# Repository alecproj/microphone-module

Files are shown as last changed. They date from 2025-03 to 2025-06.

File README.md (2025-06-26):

<div align="center">

# Smart Home Microphone Module
English | [Русский](./README.ru.md)
</div>

**Smart Home Microphone Module** is a compact IoT device based on the ESP32-S3 microcontroller, designed for use in voice-controlled systems, audio monitoring, and integration with smart-home infrastructure. The device captures ambient sound, isolates voice data, processes it, and transmits it over a distributed network.

> [!NOTE]  
> This project is based on the [voice_activity_detection](https://github.com/espressif/esp-skainet/tree/master/examples/voice_activity_detection) example from Espressif’s esp-skainet repository.

# Overview

The project comprises the following components:
- [Microphone Module](#microphone-module) (source code, schematic, PCB layout, enclosure)
- [Server](#server) (server-side source code)
- [voice_activity_detection Example](#voice_activity_detection-example) from Espressif, adapted for DevKit ESP32-S3 with one or two INMP441 MEMS microphones

## Microphone Module

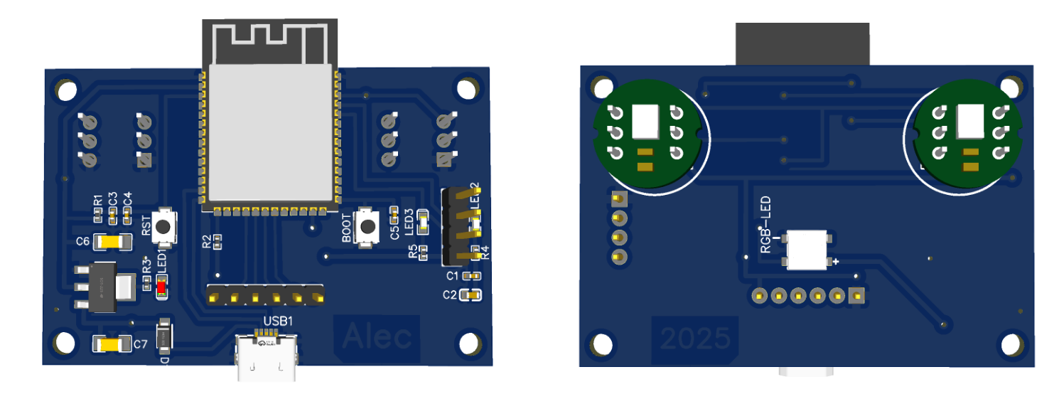
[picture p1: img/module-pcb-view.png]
Microphone module printed circuit board
 
The core components of the device are the `ESP32-S3-WROOM-N16R8` module and two I²S MEMS microphones `INMP441`.

> [!WARNING]  
> This project works **only** with an ESP32 variant that supports **at least 4 MB of PSRAM**!

The module reads audio data from the I²S microphones and processes it using Espressif’s **Audio Front End ([AFE](https://docs.espressif.com/projects/esp-sr/en/latest/esp32s3/audio_front_end/README.html))**. During processing, it performs **Voice Activity Detection (VAD)** and **Noise Suppression (NS)**. The voice data then undergoes **Automatic Gain Control (AGC)**, is converted to mono, packaged into **RTP packets**, and sent to the server over Wi-Fi via **UDP**.

Schematic of AFE audio processing:  
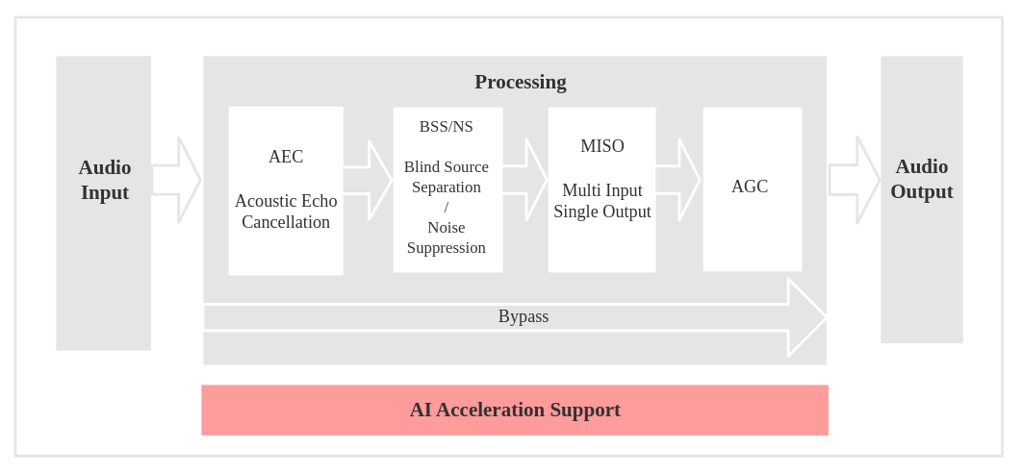
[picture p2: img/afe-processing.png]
AFE audio processing schematic


The project also includes a server application that runs on the local network and performs **speech recognition**.

Key features of the device:
-  Audio processing: VAD / NS / AGC / MISO
-  Logging processed voice data to an SD card (for debugging)
-  Transmitting only voice-active raw PCM data over Wi-Fi (UDP/RTP)

> [!TIP]  
> You can easily reproduce this on a breadboard and test it yourself.  
> Check the [module/](./module) directory for the microphone module’s source code and its **README** with quick-start setup instructions.

### Schematic

> [!CAUTION]  
> There may be errors in the schematic or PCB layout. Before fabricating the PCB, we recommend consulting a professional!  
> See the [implementation notes](./pcb/README.md).

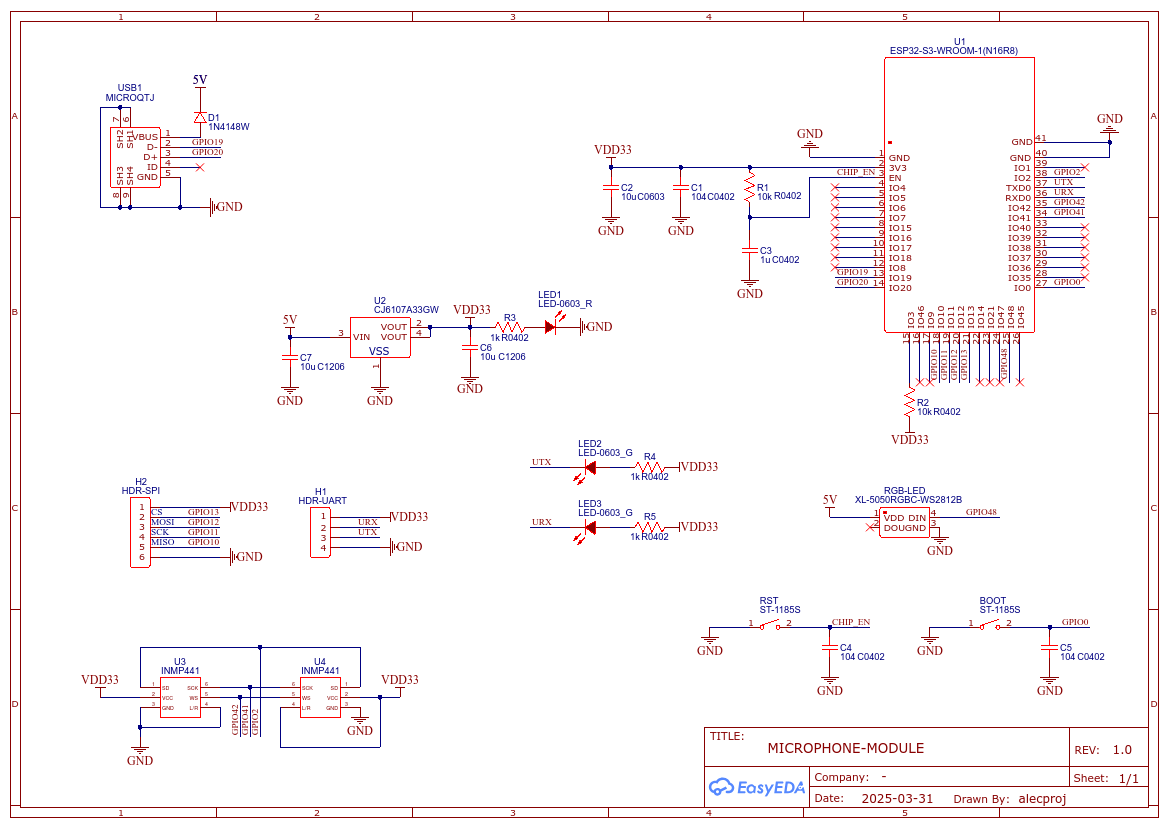
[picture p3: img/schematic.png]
Schematic diagram of the device


### Enclosure

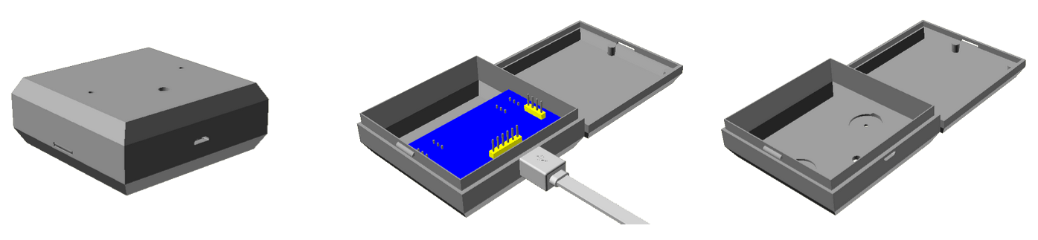
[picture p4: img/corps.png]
Enclosure of the device


## Server

The **server application**, written in Python, receives RTP packets from the device over the local network. Depending on user configuration, it can:
- play back the incoming audio in real time,
- save it to a file,
- perform offline speech recognition using the [VOSK API](https://github.com/alphacep/vosk-api) framework.

> [!TIP]  
> See the [server/](./server) directory for the server application’s source code and its **README** with quick-start setup instructions.

## voice_activity_detection example

The original **VAD** example from Espressif’s [esp-skainet](https://github.com/espressif/esp-skainet) repository supports only official evaluation boards (Korvo, Eye, etc.). In this project, it has been extended to run on **custom boards** (including the ESP32 DevKit) with one or two **INMP441** microphones (or other I²S MEMS mics).

> [!TIP]  
> See the [examples/voice_activity_detection](./examples/voice_activity_detection) directory for the example’s description, source code, and its **README** with quick-start setup instructions.

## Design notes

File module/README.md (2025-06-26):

<div align="center">

# Module Firmware
English | [Русский](./README.ru.md)
</div>

# Overview

This section covers the ESP32-S3 firmware implementing the Smart Home Microphone Module with the following functionality:
- 🎙️ Audio capture via I²S microphone (e.g., INMP441) with multi-channel input support
- 🧠 Audio processing using Espressif’s ESP-SR (Speech Recognition) library:
- 🧠 VAD (Voice Activity Detection)    
- 🌐 Audio transmission over the network using RTP and UDP protocols
- 💾 Debug logging of raw PCM data to an SD card (optional)

### Key Technologies

- [ESP-IDF](https://github.com/espressif/esp-idf) – Development framework for ESP32
- [ESP-SR](https://github.com/espressif/esp-sr) – Espressif’s audio-processing library
- [RTP](https://en.wikipedia.org/wiki/Real-time_Transport_Protocol) – Real-time audio transport protocol
- [FATFS](https://docs.espressif.com/projects/esp-idf/en/v5.4.2/esp32s3/api-reference/storage/fatfs.html) – File system for SD-card access
- [FreeRTOS](https://docs.espressif.com/projects/esp-idf/en/v5.4.2/esp32s3/api-reference/system/freertos.html) – Real-time OS for multi-core processing

### Use Cases

1. Voice-control systems with remote processing
2. Lecture-recording devices streaming to a server
3. Real-time audio-monitoring systems

### Implementation Highlights

1. Dual-core architecture:
    ```c
    xTaskCreatePinnedToCore(&feed_Task, ...);  // Core 0: capture
    xTaskCreatePinnedToCore(&fetch_Task, ...); // Core 1: processing
    ```    
2. Efficient memory management:
    - Statically allocated buffers
    - Ring buffers for audio data
    - Minimal data copying
3. Fault tolerance:
    - Packet-integrity checks
    - Automatic driver reinitialization
    - Buffer-overflow protection

### Operation Modes

1. **Direct streaming to server**  
    Module → Wi-Fi → RTP/UDP → Recognition server
2. **Local storage**  
    Module → SD Card
3. **Hybrid mode**  
    Module → (Network + SD Card) in parallel

### Firmware Architecture Diagram

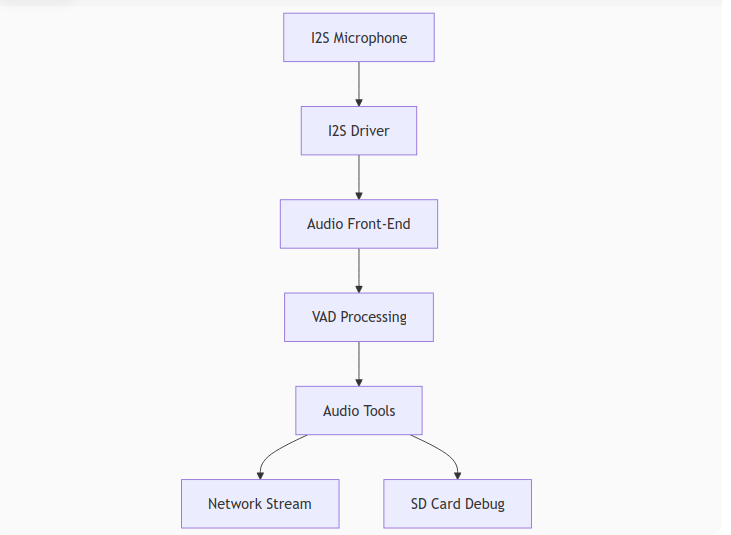
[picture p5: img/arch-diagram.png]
Firmware Architecture Diagram

# Get started

## Hardware Preparation

You will need:
- An ESP32 development board with **at least 4 MB PSRAM** (recommended **ESP32-S3-N16-R8**)
- Two **INMP441** microphones
- An SPI SD-card adapter (_optional, for debugging_)

### Microphone Connection

Wire the microphones as shown below:  
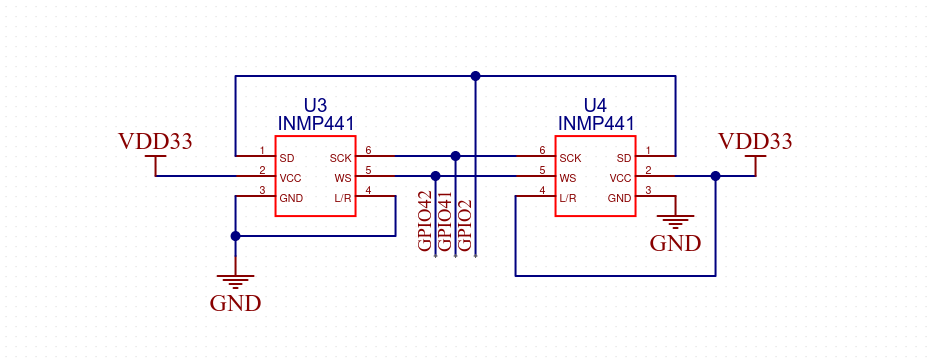
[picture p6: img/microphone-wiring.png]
Microphone Wiring


**Left microphone pinout:**

|Microphone Pin|ESP32-S3 Pin|
|---|---|
|SD|GPIO2|
|VCC|3v3|
|GND|GND|
|SCK|GPIO41|
|WS|GPIO42|
|L/R|GND|

**Right microphone pinout:**

|Microphone Pin|ESP32-S3 Pin|
|---|---|
|SD|GPIO2|
|VCC|3v3|
|GND|GND|
|SCK|GPIO41|
|WS|GPIO42|
|L/R|3v3|

> [!NOTE]  
> You can change the microphone pin assignments in [`module/i2s/i2s_input.h`](./i2s/i2s_input.h) under the `I2S interface GPIO pin assignments` section.

### SD-Card Adapter Connection

**Adapter pinout:**

|Adapter Pin|ESP32-S3 Pin|
|---|---|
|CS|GPIO13|
|SCK|GPIO11|
|MOSI|GPIO12|
|MISO|GPIO10|
|VCC|3v3|
|GND|GND|

> [!NOTE]  
> You can change the SD-card adapter pin assignments in [`module/sd_card/sdcard.h`](./sd_card/sdcard.h) under the `SD Card SPI interface configuration` section.

## Software Preparation

### Install ESP-IDF

To flash the microcontroller and configure the project, install the [ESP-IDF framework](https://docs.espressif.com/projects/esp-idf/en/v5.4.2/esp32s3/get-started/index.html) version **5.0 or newer**.

### Project Setup

1. Clone the repository:
	```sh
    git clone https://github.com/alecproj/microphone-module.git
	```
2. If you plan to use the module with your computer acting as the server on the local network, it’s recommended to first [install and configure the server](../server/README.md).
3. Change into the module directory:
    ```sh
    cd microphone-module/module
    ```
4. Set up ESP-IDF environment variables (see the [official guide](https://docs.espressif.com/projects/esp-idf/en/v5.4.2/esp32s3/get-started/linux-macos-setup.html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)).
5. Configure the project:
    ```sh
    idf.py set-target esp32s3
    idf.py menuconfig
    ```
    In the **Example Connection Configuration** section, set your Wi-Fi parameters if you plan to stream to the server.
6. In [`./main/main.c`](./main/main.c), adjust the configuration switches as needed:
    ```c
    // Configuration switches
    #define SD_FOR_DEBUG_EN 0  // Enable SD card logging for debug (0=disabled)
    #define NETWORK_EN      1  // Enable network streaming (1=enabled)
    ```

> [!NOTE]  
> For logging to SD card, ensure the SPI-SD adapter is connected.

7. In [`../network/network_stream.h`](./network/network_stream.h), set your computer’s IP address:
    ```c
    #define SERVER_IP "192.168.0.175"  // Default server IP address
    ```
8. Build and flash the board:
    ```sh
    idf.py build
    idf.py flash monitor
    ```

# Troubleshooting

## Wi-Fi Connection Issues

1. Double-check your settings in the **Example Connection Configuration** menuconfig. Ensure the **WiFi scan threshold** matches your network’s parameters.
2. Make sure no metallic objects (wires, breadboards, PCB copper areas, etc.) are near the ESP32 antenna.
3. Reserve a static IP for the ESP32 in your router’s DHCP settings.
4. Run the official ESP-IDF examples [scan](https://github.com/espressif/esp-idf/tree/master/examples/wifi/scan) and [station](https://github.com/espressif/esp-idf/tree/master/examples/wifi/getting_started/station) to find the optimal module placement.

> [!NOTE]  
> Common stability issues with the ESP32’s onboard antenna stem from nearby metal objects. For robust connectivity, consider using a module with an external antenna.

## SD-Card SPI Adapter Issues

1. Verify the adapter wiring against the schematic and the settings in [`module/sd_card/sdcard.h`](./sd_card/sdcard.h) under `SD Card SPI interface configuration`.
2. Use the shortest possible wires (no longer than 10 cm).
3. Manually format the SD card as FAT32 using your OS tools.
4. Prefer SD cards up to 8 GB in capacity.
5. If issues persist, lower the SPI bus speed (see the sdspi example README in ESP-IDF: [sdspi](https://github.com/espressif/esp-idf/tree/master/examples/storage/sd_card/sdspi)).

> [!NOTE]  
> Not all SD cards support SPI mode. Check your card’s datasheet. Card-adapter compatibility can vary, so you may need to test cards from different manufacturers.
# TODO

- Add LED status indication
- Implement custom Wi-Fi connection logic
- Integrate automatic gain control (AGC)
- Add project configuration via `Kconfig`
- Implement an OTA update system

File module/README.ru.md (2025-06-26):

<div align="center">

# Прошивка модуля
[English](./README.md) | Русский
</div>

# Обзор

Данный раздел посвящен прошивке для ESP32-S3, которая реализует микрофонный модуль умного дома со следующей функциональностью:
- 🎙️ Захват аудио через I2S-микрофон (например, INMP441) с поддержкой многоканального ввода
- 🧠 Обработка звука с использованием библиотеки ESP-SR (Speech Recognition) от Espressif:
- 🧠 VAD (Voice Activity Detection) для обнаружения речи
- 🌐 Передача аудио по сети с использованием протоколов RTP и UDP
- 💾 Отладочная запись сырых PCM-данных на SD-карту (опционально)

### Ключевые технологии

- [ESP-IDF](https://github.com/espressif/esp-idf) - Фреймворк для разработки под ESP32
- [ESP-SR](https://github.com/espressif/esp-sr) - Библиотека обработки звука от Espressif
- [RTP](https://en.wikipedia.org/wiki/Real-time_Transport_Protocol) - Протокол реального времени для передачи аудио
- [FATFS](https://docs.espressif.com/projects/esp-idf/en/v5.4.2/esp32s3/api-reference/storage/fatfs.html) - Файловая система для работы с SD-картой
- [FreeRTOS](https://docs.espressif.com/projects/esp-idf/en/v5.4.2/esp32s3/api-reference/system/freertos.html) - Операционная система реального времени для многоядерной обработки
### Сфера применения

1. Системы голосового управления с удаленной обработкой
2. Устройства для записи лекций с передачей на сервер
3. Системы аудиомониторинга в реальном времени

### Особенности реализации

1. Двухядерная архитектура:
```c
    xTaskCreatePinnedToCore(&feed_Task, ...);  // Core 0: захват
    xTaskCreatePinnedToCore(&fetch_Task, ...); // Core 1: обработка
```
2. Эффективное управление памятью:
    - Статическое выделение буферов
    - Кольцевые буферы для аудиоданных
    - Минимизация копирования данных
3. Отказоустойчивость:
    - Проверка целостности пакетов
    - Автоматическая реинициализация драйверов
    - Защита от переполнения буферов

### Сценарии использования

1. **Прямая передача на сервер**:
	Module → Wi-Fi → RTP/UDP → Сервер распознавания
2. **Локальное хранение**:
	Module → SD Card
3. **Гибридный режим**:
	Module → (Сеть + SD Card) параллельно

### Диаграма архитектуры прошивки
Диаграма архитектуры прошивки
# Быстрый старт
## Подготовка оборудования

Вам понадобится:
- Отладочная плата с микроконтроллером **ESP32** с поддержкой **PSRAM не менее 4 МБ** (рекомендуется **ESP32-S3-N16-R8**)
- Два микрофона **INMP441**
- SPI-адаптер SD-карт (*опционально, для отладки*)
### Подключение микрофонов
Подключите микрофоны согласно приведённой ниже схеме:
Схема подключения микрофонов

**Таблица подключения левого микрофона:**

| Контакт микрофона | Контакт ESP32-S3 |
| --- | --- |
| SD | GPIO2 |
| VCC | 3v3 |
| GND | GND |
| SCK | GPIO41 |
| WS | GPIO42 |
| L/R | GND |

**Таблица подключения правого микрофона:**

| Контакт микрофона | Контакт ESP32-S3 |
| --- | --- |
| SD | GPIO2 |
| VCC | 3v3 |
| GND | GND |
| SCK | GPIO41 |
| WS | GPIO42 |
| L/R | 3v3 |
>[!NOTE]
>Изменить назначение пинов микрофонов можно в файле [`module/i2s/i2s_input.h`](./i2s/i2s_input.h) в разделе `I2S interface GPIO pin assignments`.
### Подключение адаптера SD-карт
**Таблица подключения адаптера:**

| Контакт адаптера | Контакт ESP32-S3 |
| --- | --- |
| CS | GPIO13 |
| SCK | GPIO11 |
| MOSI | GPIO12 |
| MISO | GPIO10 |
| VCC | 3v3 |
| GND | GND |
>[!NOTE]
>Изменить пины подключения SD-адаптера можно в файле [`module/sd_card/sdcard.h`](./sd_card/sdcard.h) в разделе `SD Card SPI interface configuration`
## Подготовка ПО
### Установка ESP-IDF

Для прошивки микроконтроллера и конфигурации проекта необходим установленный фреймворк [ESP-IDF](https://docs.espressif.com/projects/esp-idf/en/v5.4.2/esp32s3/get-started/index.html) версии **не ниже 5.0**.

### Подготовка проекта

1. Клонируйте репозиторий проекта:
```sh
git clone https://github.com/alecproj/microphone-module.git
```
2. Если вы хотите использовать модуль для взаимодействия с сервером, в роли которого будет выступать ваш компьютер в локальной сети, то рекомендуется сначала [установить и настроить сервер](../server/README.ru).
3. Перейдите в директорию модуля:
```sh
cd microphone-module/module
```
4. Настройте переменные среды ESP-IDF (см. [официальное руководство](https://docs.espressif.com/projects/esp-idf/en/v5.4.2/esp32s3/get-started/linux-macos-setup.html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))
5. Выполните настройку проекта:
```sh
idf.py set-target esp32s3
idf.py menuconfig
```
В разделе `Example Connection Configuration` укажите параметры сети, если планируется подключение к серверу по Wi-Fi.
6. Перейдите в папку `./main`, откройте файл [`main.c`](./main/main.c) и настройте параметры:
```c
// Configuration switches
#define SD_FOR_DEBUG_EN 0  // Enable SD card logging for debug (0=disabled)
#define NETWORK_EN 1       // Enable network streaming (1=enabled)
```
>[!NOTE]
>Для записи на SD-карту должен быть подключён SPI-адаптер.

7. Перейдите в папку `../network`, откройте файл [`network_stream.h`](./network/network_stream.h) и укажите ip-адрес вашего компьютера:
```c
#define SERVER_IP "192.168.0.175"     // Default server IP address
```
8. Скомпилируйте проект и прошейте плату:
```sh
idf.py build
idf.py flash monitor
```
# Устранение неисправностей
## Проблемы с Wi-Fi соединением

1. Перепроверьте корректность настроек в разделе `Example Connection Configuration` menuconfig. Значения в разделе `WiFi scan threshold` должны соответствовать параметрам вашей WiFi сети.
2. Убедитесь, что рядом с антенной ESP32 нет металлических предметов (включая провода, макетные платы и другие элементы, способные экранировать сигнал).
3. Зарезервируйте статический IP-адрес для ESP32 в настройках DHCP-сервера вашего роутера.
4. Запустите официальные примеры [scan](https://github.com/espressif/esp-idf/tree/master/examples/wifi/scan) и [station](https://github.com/espressif/esp-idf/tree/master/examples/wifi/getting_started/station) из репозитория ESP-IDF и подберите оптимальное расположение модуля.

> [!NOTE]  
> Наиболее распространённые проблемы со стабильностью Wi-Fi при использовании ESP32 с интегрированной антенной связаны с экранирующими объектами рядом (макетные платы, провода, металлические полигоны). Рекомендуется использовать модули с внешней антенной для надёжного соединения.
## Проблемы с SPI-адаптером SD-карты

1. Проверьте правильность подключения адаптера согласно схеме и настройкам в файле [`module/sd_card/sdcard.h`](./sd_card/sdcard.h), раздел `SD Card SPI interface configuration`.
2. Используйте максимально короткие провода (не более 10 см).
3. Отформатируйте SD-карту вручную в файловую систему FAT32 средствами вашей операционной системы.
4. По возможности используйте SD-карты объёмом до 8 ГБ.
5. Попробуйте снизить скорость передачи данных по SPI (см. [README примера sdspi](https://github.com/espressif/esp-idf/tree/master/examples/storage/sd_card/sdspi)).

> [!NOTE]  
> Не все SD-карты поддерживают режим SPI. Ознакомьтесь с технической документацией вашей карты. Также возможны проблемы совместимости между конкретной картой и адаптером. Иногда необходимо протестировать несколько карт разных производителей, прежде чем найти совместимую.

# TODO

- Добавить светодиодную индикацию состояния (LED-индикация)
- Реализовать собственную логику подключения к Wi-Fi
- Внедрить автоматическую регулировку усиления (AGC, Auto Gain Control)
- Добавить возможность конфигурации проекта через `Kconfig`
- Внедрить систему OTA-обновлений

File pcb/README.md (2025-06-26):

<div align="center">

# Printed Circuit Board
English | [Русский](./README.ru.md)
</div>

> [!CAUTION]  
> There may be errors in the schematic or PCB layout. Before fabricating the PCB, we recommend consulting a professional! 

> [!WARNING]  
> Please read the [Known Issues](#-known-issues) section!

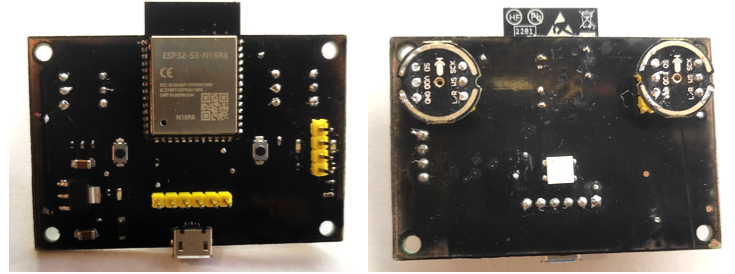
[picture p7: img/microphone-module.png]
Microphone Module


# Implementation Notes

## Components

The use of 0402 SMD components was chosen to reduce the cost of home PCB manufacturing. All passive components were desoldered from a widely available Chinese DevKit C-1 board (a clone of the original Espressif module). Other than that development board and two INMP441 microphones, no additional components are needed to build this PCB at home.

> [!NOTE]  
> The schematic and datasheet for the reference board version can be found in the repository:  
> [https://github.com/rtek1000/YD-ESP32-23.git](https://github.com/rtek1000/YD-ESP32-23.git)  
> This design served as a base for the microphone module.

## 🚨 Known Issues

The PCB layout does not fully follow the [Espressif guidelines for placing ESP32-S3-WROOM-1 modules](https://docs.espressif.com/projects/esp-hardware-design-guidelines/en/latest/esp32s3/pcb-layout-design.html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). As a result, the board exhibits degraded Wi-Fi signal quality. Ground planes, traces, and components located near the right side of the onboard antenna create parasitic structures and partially shield the signal.

### Possible Solutions:

- **Replace the module with [ESP32-S3-WROOM-1U](https://www.espressif.com/sites/default/files/documentation/esp32-s3-wroom-1_wroom-1u_datasheet_en.pdf)**, which supports external antennas. Plan antenna placement accordingly.
- **Redesign the PCB layout**: remove ground planes and traces in the antenna zone, or rework the component placement based on Espressif's recommendations.

> [!TIP]  
> Even with perfect layout, the onboard antenna is limited in performance. Therefore, **switching to the external-antenna variant (WROOM-1U) is the recommended approach**.

## PCB Schematic

PCB Schematic

## PCB Layout

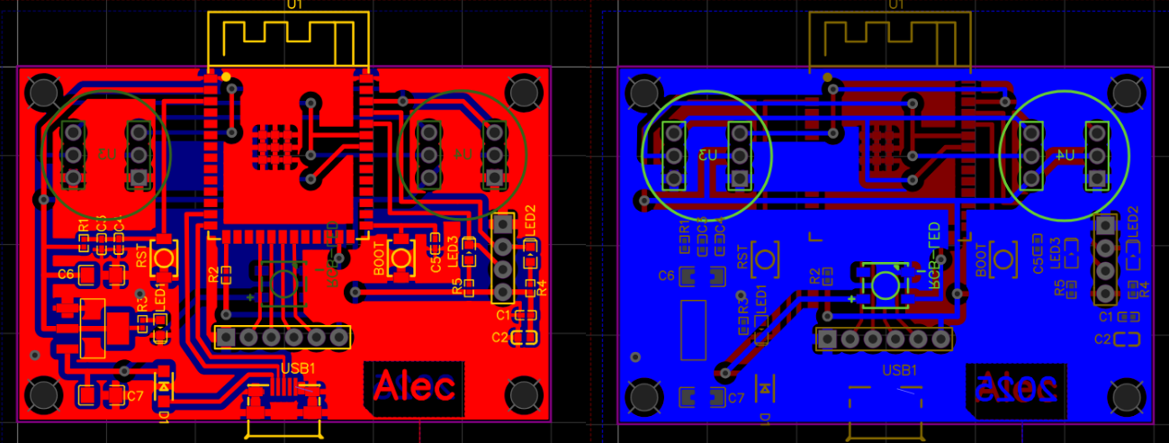
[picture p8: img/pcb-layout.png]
PCB Layout


## PCB Manufacturing Process

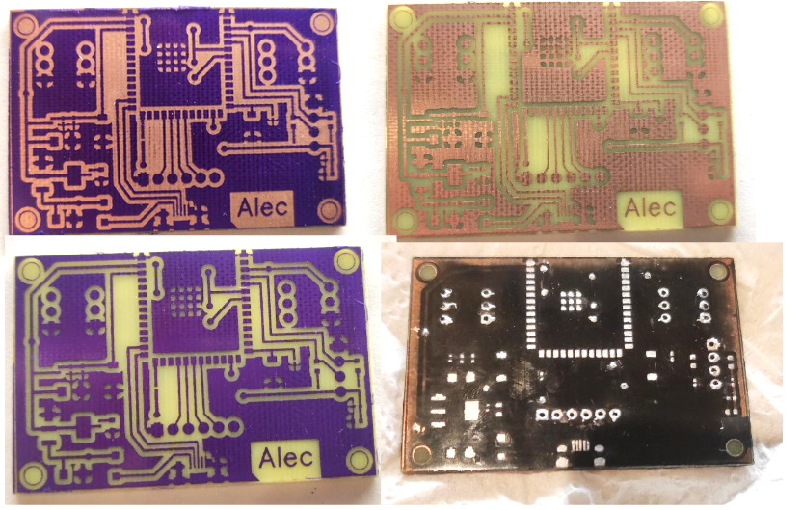
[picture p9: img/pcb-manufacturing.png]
PCB Manufacturing Process


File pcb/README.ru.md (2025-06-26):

<div align="center">

# Печатная плата
[English](./README.md) | Русский
</div>

> [!CAUTION]
> Схема и разводка печатной платы могут содержать ошибки. Перед воспроизведением печатной платы рекомендуется проконсультироваться с профессионалом!

> [!WARNING]
> Ознакомьтесь с содержимым раздела [Известные проблемы](#-известные-проблемы)!

Микрофонный модуль
# Заметки о реализации

## Компоненты

Выбор SMD-компонентов форм-фактора 0402 обусловлен стремлением удешевить производство печатной платы в домашних условиях. Все обвязочные компоненты были перепаяны с популярной на китайском рынке отладочной платы DevKit C-1 (клон оригинального модуля от Espressif). Помимо такой отладочной платы и двух микрофонов INMP441, для домашнего изготовления этой печатной платы дополнительных компонентов не потребуется.

>[!NOTE]
Схема и даташит к используемой версии платы размещены в репозитории:  
[https://github.com/rtek1000/YD-ESP32-23.git](https://github.com/rtek1000/YD-ESP32-23.git)  
Они были взяты за основу при разработке микрофонного модуля.
## 🚨 Известные проблемы

При разводке печатной платы не были учтены [рекомендации Espressif по размещению модулей ESP32-S3-WROOM-1](https://docs.espressif.com/projects/esp-hardware-design-guidelines/en/latest/esp32s3/pcb-layout-design.html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). В результате на разработанной плате наблюдаются проблемы с качеством Wi-Fi сигнала. Земляные полигоны, дорожки и компоненты, расположенные справа от антенны, создают паразитные антенны и частично экранируют сигнал.

### Возможные решения:

- **Заменить модуль на [ESP32-S3-WROOM-1U](https://www.espressif.com/sites/default/files/documentation/esp32-s3-wroom-1_wroom-1u_datasheet_en.pdf)** (с возможностью подключения выносной антенны) и продумать её размещение в корпусе.
- **Переработать топологию печатной платы**: удалить земляные полигоны и дорожки в зоне антенны, либо полностью изменить расположение компонентов в соответствии с рекомендациями Espressif.

> [!TIP] 
> Учитывая ограниченные возможности встроенной антенны даже при идеальной разводке, **наиболее предпочтительным вариантом является переход на модуль с внешней антенной (WROOM-1U)**.

## Схема печатной платы

Схема печатной платы
## Разводка печатной платы

Разводка печатной платы
## Процесс изготовления печатной платы

Процесс изготовления печатной платы

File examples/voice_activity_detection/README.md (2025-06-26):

<div align="center">

# Voice Activity Detection
English | [Русский](./README.ru.md)
</div>

This example is used to test VAD (Voice Activity Detection). Now two types of VAD are supported: WebRTC VAD and Espressif's vadnet1. You can select the desired version through menuconfig. Compared to WebRTC noise, vadnet1 can filter out more noise, but it also consumes more CPU resources.
# Quick Start

## Hardware Preparation

To run this example, you need to have an **ESP32** or **ESP32-S3** (ESP32-S3 recommended) development board with one or two **INMP441** microphones (or other I²S MEMS mics).
## Software Preparation
### Microphone Module

Clone this project as follows:
```sh
git clone https://github.com/alecproj/microphone-module.git
```
Change into the example directory:
```sh
cd microphone-module/examples/voice_activity_detection
```
### ESP-IDF

 [ESP-IDF v5.0](https://github.com/espressif/esp-idf/tree/release/v5.0) (or newer) are supported. If you had already configured ESP-IDF before, and do not want to change your existing one, you can configure the `IDF_PATH` environment variable to the path to ESP-IDF. 

>[!NOTE]
For details on how to set up the ESP-IDF, please refer to [ESP-IDF framework](https://docs.espressif.com/projects/esp-idf/en/v5.4.2/esp32s3/get-started/index.html)
### Configure 

Select board and wake words
```
idf.py set-target esp32s3
idf.py menuconfig

# Select audio board
Audio Media HAL -> Audio hardware board -> ESP32-S3-1mic

# Load vadnet1 model
ESP Speech Recognition -> Select voice activity detection -> voice activity detection (vadnet1 medium)
```
### Setting

You can set the following parameters in the config file:
```
    vad_init;           // Whether to init vad
    vad_mode;           // The value can be: VAD_MODE_0, VAD_MODE_1, VAD_MODE_2, VAD_MODE_3, VAD_MODE_4
                        // The larger the mode, the higher the speech trigger probability.

    vad_model_name;     // The model name of vad, If it is null, WebRTC VAD will be used.
    vad_min_speech_ms;  // The minimum duration of speech in ms. It should be bigger than 32 ms, default: 128 ms
    vad_min_noise_ms;   // The minimum duration of noise or silence in ms. It should be bigger than 64 ms, default: 1000 ms
    vad_delay_ms;       // The delay of the first speech frame in ms, default: 128 ms
                            // If you find vad cache can not cover all speech, please increase this value.
```

There are two issues in the VAD settings that can cause a delay in the first frame trigger of speech.
1. The inherent delay of the VAD algorithm itself. VAD cannot accurately trigger speech on the first frame and may delay by 1 to 3 frames.
2. To avoid false triggers, the VAD is triggered when the continuous trigger duration reaches the `vad_min_speech_ms` parameter in AFE configuation.
Due to the above two reasons, directly using the first frame trigger of VAD may cause the first word to be truncated. 
To avoid this situation, AFE V2.0 has added a VAD cache. You can determine whether a VAD cache needs to be saved by checking the vad_cache_size.

### build&flash

Build the project and flash it to the board, then run the monitor tool to view the output via serial port:

```
idf.py flash monitor 
```

(To exit the serial monitor, type ``Ctrl-]``.)

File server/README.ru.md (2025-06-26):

<div align="center">

# Аудио сервер
[English](./README.md) | Русский
</div>

# Обзор

**Сервер для приёма голосовых аудиоданных** обладает следующими ключевыми функциями:
- 🌐 Приём аудиопотока по UDP (протокол RTP)
- 🔊 Воспроизведение аудио в реальном времени с использованием PyAudio
- 💾 Запись сырого аудиопотока в файл формата PCM
- 🎙️ Офлайн-распознавание речи с помощью [Vosk API](https://github.com/alphacep/vosk-api)
- ⚙️ Конфигурация через аргументы командной строки
- 🛡️ Корректная обработка сигналов завершения (SIGINT, SIGTERM)

### Зависимости
- Python 3.10+ (проверьте версию: `python --version`)
- [VoskAPI](https://alphacephei.com/vosk/) 
- [PyAudio](https://people.csail.mit.edu/hubert/pyaudio/)
- [NumPy](https://numpy.org)
- [RTP](https://github.com/bbc/rd-apmm-python-lib-rtp)
# Быстрый старт
## Установка

1. Клонируйте репозиторий:
```bash
git clone https://github.com/alecproj/microphone-module
cd microphone-module/server
```
2. (Опционально) Создайте виртуальное окружение:
```bash
python -m venv pyvenv
# Для Linux/macOS:
source pyvenv/bin/activate
# Для Windows:
.\pyvenv\Scripts\activate
```
3. Установите зависимости:
```bash
pip install -r requirements.txt
```
4. Установите модель Vosk:
```bash
# Замените модель при необходимости
wget https://alphacephei.com/vosk/models/vosk-model-ru-0.42.zip
unzip vosk-model-ru-0.42.zip
mv vosk-model-ru-0.42 model
```
> [!TIP] 
> Доступные модели: [alphacephei.com/vosk/models](https://alphacephei.com/vosk/models)

> [!NOTE]
> Если у вас нет `wget`, скачайте модель вручную и распакуйте в папку `model`.

5. Укажите путь к модели Vosk в файле [`server.py`](./server.py):
```python
    VOSK_MODEL_PATH: str = "model/vosk-model-ru-0.42"
```
## Использование

Запустите сервер, выполнив:
```bash
python server.py [-h] [--disable-recognition] [--disable-playback] [--disable-file-write] [--log-level {DEBUG,INFO,WARNING,ERROR,CRITICAL}]
```
**Описание аргументов командной строки:**

| Аргумент | Описание | По умолчанию |
| --- | --- | --- |
| -h, --help | Помощь и завершение | - |
| `--disable-recognition` | Отключить распознавание речи | Включено |
| `--disable-playback` | Отключить воспроизведение аудио | Включено |
| `--disable-file-write`  | Отключить запись аудио в файл (PCM) | Включено |
| `--log-level` | Уровень логирования (DEBUG, INFO, WARNING, ERROR, CRITICAL) | INFO |

**Вывод в консоль при успешном запуске сервера:**
```sh
2025-06-26 16:49:28,664 - RTPServer - INFO - Server started on 0.0.0.0:8765 with settings:
2025-06-26 16:49:28,664 - RTPServer - INFO -  Recognition: True
2025-06-26 16:49:28,665 - RTPServer - INFO -  Playback: True
2025-06-26 16:49:28,665 - RTPServer - INFO -  File write: True
LOG (VoskAPI:ReadDataFiles():model.cc:213) Decoding params beam=13 max-active=7000 lattice-beam=6
LOG (VoskAPI:ReadDataFiles():model.cc:216) Silence phones 1:2:3:4:5:6:7:8:9:10
LOG (VoskAPI:RemoveOrphanNodes():nnet-nnet.cc:948) Removed 1 orphan nodes.
LOG (VoskAPI:RemoveOrphanComponents():nnet-nnet.cc:847) Removing 2 orphan components.
LOG (VoskAPI:Collapse():nnet-utils.cc:1488) Added 1 components, removed 2
LOG (VoskAPI:ReadDataFiles():model.cc:248) Loading i-vector extractor from model/vosk-model-ru-0.42/ivector/final.ie
LOG (VoskAPI:ComputeDerivedVars():ivector-extractor.cc:183) Computing derived variables for iVector extractor
LOG (VoskAPI:ComputeDerivedVars():ivector-extractor.cc:204) Done.
LOG (VoskAPI:ReadDataFiles():model.cc:279) Loading HCLG from model/vosk-model-ru-0.42/graph/HCLG.fst
LOG (VoskAPI:ReadDataFiles():model.cc:297) Loading words from model/vosk-model-ru-0.42/graph/words.txt
LOG (VoskAPI:ReadDataFiles():model.cc:308) Loading winfo model/vosk-model-ru-0.42/graph/phones/word_boundary.int
LOG (VoskAPI:ReadDataFiles():model.cc:315) Loading subtract G.fst model from model/vosk-model-ru-0.42/rescore/G.fst
LOG (VoskAPI:ReadDataFiles():model.cc:317) Loading CARPA model from model/vosk-model-ru-0.42/rescore/G.carpa
LOG (VoskAPI:ReadDataFiles():model.cc:323) Loading RNNLM model from model/vosk-model-ru-0.42/rnnlm/final.raw
2025-06-26 16:49:51,182 - RTPServer - INFO - Recognizer started
```
# Для разработчиков

## Конфигурация

 Основные параметры конфигурации изменяются в коде [`server.py`](./server.py) (класс `Config`), например:
- `HOST` и `PORT` для UDP сервера
- Параметры аудио (формат, каналы, частота дискретизации, размер буфера)
- Путь к модели Vosk (`VOSK_MODEL_PATH`)

```python
class Config:
    HOST: str = "0.0.0.0"
    PORT: int = 8765
    AUDIO_FORMAT: int = pyaudio.paInt16
    CHANNELS: int = 1
    SAMPLE_RATE: int = 16000
    FRAMES_PER_BUFFER: int = 4096 
    MIN_PACKET_LEN: int = 512
    MAX_PACKET_LEN: int = 1024
    LOG_LEVEL: str = "INFO"
    VOSK_MODEL_PATH: str = "model/vosk-model-ru-0.42"
    ENABLE_RECOGNITION: bool = True
    ENABLE_PLAYBACK: bool = True
    ENABLE_FILE_WRITE: bool = True

```
## Советы по отладке

1. Проверка входящего трафика:
```sh
tcpdump -i any udp port 8765 -vv -X
```
2. Прослушивание в обход сервера через ffmpeg
```sh
ffmpeg -f alsa -i default -acodec pcm_s16le -ar 16000 -ac 1 -f rtp rtp://127.0.0.1:8765
```
3. Воспроизведение записанного PCM:
```sh
ffplay -f s16le -ar 16000 TEST.PCM
```
4. Тестирование без сети:
```sh
# В udp_server() после получения данных:
audio_streamer.process_audio(b"\x00" * 2048)  # Генерация тишины
```
# TODO

-  Добавить валидацию источников
-  Внедрить шифрование данных
-  Реализовать мониторинг трафика и других метрик
-  Написать тесты

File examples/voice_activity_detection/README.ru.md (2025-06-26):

<div align="center">

# Обнаружение голосовой активности
[English](./README.md) | Русский
</div>

Этот пример используется для тестирования детекции голосовой активности (Voice Activity Detection, VAD). Поддерживаются два типа VAD: WebRTC VAD и vadnet1 от Espressif. Вы можете выбрать необходимую версию через menuconfig. По сравнению с WebRTC VAD, vadnet1 лучше фильтрует фоновые шумы, однако требует больше ресурсов CPU.

# Быстрый старт

## Подготовка оборудования

Для запуска этого примера вам понадобится плата разработки **ESP32** или **ESP32-S3** (рекомендуется ESP32-S3) с одним или двумя микрофонами **INMP441** (или другими I²S MEMS-микрофонами).

## Подготовка ПО

### Модуль микрофона

Клонируйте этот проект следующей командой:
```sh
git clone https://github.com/alecproj/microphone-module.git
```
Перейдите в директорию примера:
```sh
cd microphone-module/examples/voice_activity_detection
```
### ESP-IDF

Поддерживаются версии [ESP-IDF v5.0](https://github.com/espressif/esp-idf/tree/release/v5.0) или новее. Если вы уже настроили ESP-IDF и не хотите менять существующую конфигурацию, можете указать путь к ESP-IDF через переменную окружения `IDF_PATH`.

> [!NOTE]  
> Для подробностей по установке ESP-IDF см. [документацию ESP-IDF](https://docs.espressif.com/projects/esp-idf/en/v5.4.2/esp32s3/get-started/index.html)

### Конфигурирование

Выберите плату и модель VAD:
```
idf.py set-target esp32s3
idf.py menuconfig

# Выберите аудиоплату
Audio Media HAL -> Audio hardware board -> ESP32-S3-1mic

# Загрузите модель vadnet1
ESP Speech Recognition -> Select voice activity detection -> voice activity detection (vadnet1 medium)
```
### Параметры

В файле конфигурации можно задать следующие параметры:

```c
    vad_init;           // Инициализация VAD
    vad_mode;           // Может принимать значения: VAD_MODE_0, VAD_MODE_1, VAD_MODE_2, VAD_MODE_3, VAD_MODE_4
                        // Чем выше режим, тем выше вероятность срабатывания на речь.

    vad_model_name;     // Имя модели VAD. Если null, используется WebRTC VAD.
    vad_min_speech_ms;  // Минимальная длительность речи в мс. Должна быть больше 32 мс, по умолчанию: 128 мс
    vad_min_noise_ms;   // Минимальная длительность шума или тишины в мс. Должна быть больше 64 мс, по умолчанию: 1000 мс
    vad_delay_ms;       // Задержка до первого фрейма речи в мс, по умолчанию: 128 мс
                        // Если VAD-кеш не покрывает весь фрагмент речи, увеличьте это значение.
```

В настройках VAD есть два фактора, которые могут вызвать задержку срабатывания на первый фрейм речи:
1. Встроенная задержка самого алгоритма VAD. Алгоритм может определить начало речи с задержкой в 1–3 кадра.
2. Во избежание ложных срабатываний VAD срабатывает только при достижении непрерывной длительности речи, указанной в параметре `vad_min_speech_ms`.

Из-за этих причин прямое использование первого фрейма VAD может привести к усечению первого слова. Чтобы этого избежать, в AFE V2.0 добавлен VAD-кеш. Вы можете определить необходимость сохранения кеша по значению `vad_cache_size`.
### Сборка и прошивка

Соберите проект и прошейте плату, затем запустите монитор для просмотра вывода по последовательному порту:
```sh
idf.py flash monitor
```
(Для выхода из монитора нажмите `Ctrl-]`.)

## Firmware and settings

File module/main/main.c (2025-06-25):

#include <stdbool.h>

#include "esp_afe_sr_models.h"
#include "freertos/FreeRTOS.h"
#include "freertos/task.h"
#include "model_path.h"
#include "esp_log.h"
#include "esp_event.h"
#include "nvs_flash.h"
#include "esp_netif.h"
#include "protocol_examples_common.h"

#include "i2s_input.h"
#include "sdcard.h"
#include "audio_tools.h"
#include "network_stream.h"

// Configuration switches
#define SD_FOR_DEBUG_EN 0  // Enable SD card logging for debug (0=disabled)
#define NETWORK_EN 1       // Enable network streaming (1=enabled)

static esp_afe_sr_iface_t *afe_handle = NULL;
static const char* TAG = "module";
#if SD_FOR_DEBUG_EN
static FILE* fd = NULL;
#endif // SD_FOR_DEBUG_EN
#if NETWORK_EN
static network_data_t network_data = {0};
#endif // NETWORK_EN

/**
 * @brief Process audio data and stream to output targets
 * 
 * @param audio_data Input audio data structure
 * 
 * Performs:
 * 1. Downmix to mono (if multichannel input)
 * 2. SD card debug logging (if enabled)
 * 3. Network streaming (if enabled)
 * 4. Memory cleanup
 */
void postprocess_and_stream(audio_data_t* audio_data)
{
    esp_err_t rv = ESP_OK;
    audio_data_t output = {0};

    if (!audio_data)
    {
        ESP_LOGE(TAG, "An invalid pointer was passed to the "
                      "post processing function.");
        return;
    }

    if (audio_data->data_channels > 1)
    {
        rv = downmix_to_mono(*audio_data, &output);
        if (rv != ESP_OK)
        {
            ESP_LOGE(TAG, "An error (%s) occurred during post processing.", 
                     esp_err_to_name(rv));
            return;
        }
    }

#if SD_FOR_DEBUG_EN
    sdcard_write(output.data, 1, output.data_size, fd);
#endif // SD_FOR_DEBUG_EN

#if NETWORK_EN
    udp_send_pcm(output.data, output.data_size, &network_data);
#endif // NETWORK_EN

    free(output.data);
    output.data = NULL;
}

/**
 * @brief Task for feeding audio data to AFE (Audio Front-End)
 * 
 * @param arg AFE data handle (esp_afe_sr_data_t)
 * 
 * Continuously:
 * 1. Reads audio from I2S input
 * 2. Feeds data to AFE processing pipeline
 */
void feed_Task(void *arg)
{
    esp_afe_sr_data_t *afe_data = arg;
    int feed_chunksize = afe_handle->get_feed_chunksize(afe_data);
    // TODO: configuration compliance check
    int feed_nch = afe_handle->get_feed_channel_num(afe_data);
    int16_t *feed_buff = (int16_t *) malloc(feed_chunksize * feed_nch * sizeof(int16_t));
    assert(feed_buff);

    while (1)
    {
        i2s_input_get_feed_data(
            feed_buff, 
            feed_chunksize * feed_nch * sizeof(int16_t)
        );
        afe_handle->feed(afe_data, feed_buff);
    }
    
    if (feed_buff)
    {
        free(feed_buff);
        feed_buff = NULL;
    }
    vTaskDelete(NULL);
}

/**
 * @brief Task for fetching processed audio from AFE
 * 
 * @param arg AFE data handle (esp_afe_sr_data_t)
 * 
 * Continuously:
 * 1. Fetches processed audio from AFE
 * 2. Processes VAD (Voice Activity Detection) results
 * 3. Sends valid audio segments to postprocessing
 */
void fetch_Task(void *arg)
{
    esp_afe_sr_data_t *afe_data = arg;

    while (1)
    {
        // Get processed audio results
        afe_fetch_result_t *res = afe_handle->fetch(afe_data);
        if (!res || res->ret_value == ESP_FAIL)
        {
            ESP_LOGE(TAG, "Fetch data error.");
            break;
        }

        if (res->vad_cache_size > 0)
        {
            ESP_LOGI(TAG, "VAD cache size: %d", res->vad_cache_size);
            audio_data_t audio_data = {
                .data = res->vad_cache,
                .data_size = res->vad_cache_size,
                .data_channels = afe_handle->get_feed_channel_num(afe_data),
                .target_channel = res->trigger_channel_id
            };
            postprocess_and_stream(&audio_data);
        }
        if (res->vad_state == VAD_SPEECH)
        {
            ESP_LOGI(TAG, "VAD state: speech");
            audio_data_t audio_data = {
                .data = res->data,
                .data_size = res->data_size,
                .data_channels = afe_handle->get_feed_channel_num(afe_data),
                .target_channel = res->trigger_channel_id
            };
            postprocess_and_stream(&audio_data);
        }
    }

    vTaskDelete(NULL);
}

/**
 * @brief Main application entry point
 * 
 * Initializes:
 * 1. I2S audio input
 * 2. Network connectivity (if enabled)
 * 3. SD card (if debug enabled)
 * 4. Audio Front-End processing
 * 5. Feed/fetch tasks
 */
void app_main()
{
    ESP_ERROR_CHECK(i2s_input_init());
#if NETWORK_EN
    ESP_ERROR_CHECK(nvs_flash_init());
    ESP_ERROR_CHECK(esp_netif_init());
    ESP_ERROR_CHECK(esp_event_loop_create_default());
    /* This helper function configures Wi-Fi or Ethernet, as selected in menuconfig.
     * TODO: Replace
     */
    ESP_ERROR_CHECK(example_connect());
    ESP_ERROR_CHECK(network_init(&network_data));
#endif // NETWORK_EN

#if SD_FOR_DEBUG_EN
    ESP_ERROR_CHECK(sdcard_init("/sdcard", 10));
    fd = fopen("/sdcard/TEST.pcm", "w+");
    if(fd == NULL) 
    {
        ESP_LOGE(TAG, "Error opening file.");
    }
#endif // SD_FOR_DEBUG_EN

    /* Initialize AFE Configuration */
    srmodel_list_t *models = esp_srmodel_init("model");
    afe_config_t *afe_config = afe_config_init(i2s_input_get_format(), models, AFE_TYPE_VC, AFE_MODE_HIGH_PERF);
    afe_config->vad_min_noise_ms = 1000;
    afe_config->vad_min_speech_ms = 128;
    afe_config->vad_mode = VAD_MODE_0;
    afe_config->wakenet_init = 0;

    /* Create AFE Instance */
    afe_handle = esp_afe_handle_from_config(afe_config);
    esp_afe_sr_data_t *afe_data = afe_handle->create_from_config(afe_config);
    afe_config_free(afe_config);

    /* Create Threads */
    xTaskCreatePinnedToCore(&feed_Task, "feed", 8 * 1024, (void*)afe_data, 5, NULL, 0);
    xTaskCreatePinnedToCore(&fetch_Task, "fetch", 4 * 1024, (void*)afe_data, 5, NULL, 1);
}

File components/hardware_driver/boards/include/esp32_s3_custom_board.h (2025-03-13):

/**
 * 
 * @copyright Copyright 2021 Espressif Systems (Shanghai) Co. Ltd.
 *            Modifications 2025 alecproj
 *
 *      Licensed under the Apache License, Version 2.0 (the "License");
 *      you may not use this file except in compliance with the License.
 *      You may obtain a copy of the License at
 *
 *               http://www.apache.org/licenses/LICENSE-2.0
 *
 *      Unless required by applicable law or agreed to in writing, software
 *      distributed under the License is distributed on an "AS IS" BASIS,
 *      WITHOUT WARRANTIES OR CONDITIONS OF ANY KIND, either express or implied.
 *      See the License for the specific language governing permissions and
 *      limitations under the License.
 */
#pragma once

#include "driver/gpio.h"
#include "esp_idf_version.h"
#include "esp_codec_dev.h"
#include "esp_codec_dev_defaults.h"
#include "esp_codec_dev_os.h"

/**
 * @brief ESP32-S3-CUSTOM I2C GPIO defineation
 * 
 */
#define FUNC_I2C_EN     (0)
#define I2C_NUM         (0)
#define I2C_CLK         (600000)
#define GPIO_I2C_SCL    (GPIO_NUM_NC)
#define GPIO_I2C_SDA    (GPIO_NUM_NC)

/**
 * @brief ESP32-S3-CUSTOM SDMMC GPIO defination
 * 
 * @note Only avaliable when PMOD connected
 */
#define FUNC_SDMMC_EN   (0)
#define SDMMC_BUS_WIDTH (0)
#define GPIO_SDMMC_CLK  (GPIO_NUM_NC)
#define GPIO_SDMMC_CMD  (GPIO_NUM_NC)
#define GPIO_SDMMC_D0   (GPIO_NUM_NC)
#define GPIO_SDMMC_D1   (GPIO_NUM_NC)
#define GPIO_SDMMC_D2   (GPIO_NUM_NC)
#define GPIO_SDMMC_D3   (GPIO_NUM_NC)
#define GPIO_SDMMC_DET  (GPIO_NUM_NC)

/**
 * @brief ESP32-S3-CUSTOM SDSPI GPIO definationv
 * 
 */
#define FUNC_SDSPI_EN       (1)
#define SDSPI_HOST          (SPI2_HOST)
#define GPIO_SDSPI_CS       (GPIO_NUM_2)
#define GPIO_SDSPI_SCLK     (GPIO_NUM_5)
#define GPIO_SDSPI_MISO     (GPIO_NUM_21)
#define GPIO_SDSPI_MOSI     (GPIO_NUM_18)
/**
 * @brief ESP32-S3-CUSTOM I2S GPIO defination
 * 
 */
#define FUNC_I2S_EN         (1)
#define GPIO_I2S_LRCK       (GPIO_NUM_11)
#define GPIO_I2S_MCLK       (GPIO_NUM_NC)
#define GPIO_I2S_SCLK       (GPIO_NUM_12)
#define GPIO_I2S_SDIN       (GPIO_NUM_10)
#define GPIO_I2S_DOUT       (GPIO_NUM_NC)

/**
 * @brief ESP32-S3-CUSTOM I2S GPIO defination
 * 
 */
#define FUNC_I2S0_EN         (0)
#define GPIO_I2S0_LRCK       (GPIO_NUM_NC)
#define GPIO_I2S0_MCLK       (GPIO_NUM_NC)
#define GPIO_I2S0_SCLK       (GPIO_NUM_NC)
#define GPIO_I2S0_SDIN       (GPIO_NUM_NC)
#define GPIO_I2S0_DOUT       (GPIO_NUM_NC)

#define RECORD_VOLUME   (100.0)
/**
 * @brief player configurations
 *
 */
#define PLAYER_VOLUME   (50)

/**
 * @brief ESP32-S3-HMI-DevKit power control IO
 * 
 * @note Some power control pins might not be listed yet
 * 
 */
#define FUNC_PWR_CTRL       (0)
#define GPIO_PWR_CTRL       (GPIO_NUM_NC)
#define GPIO_PWR_ON_LEVEL   (1)

#if ESP_IDF_VERSION >= ESP_IDF_VERSION_VAL(5, 0, 0)

#define I2S_CONFIG_DEFAULT(sample_rate, channel_fmt, bits_per_chan) { \
        .clk_cfg = I2S_STD_CLK_DEFAULT_CONFIG(sample_rate), \
        .slot_cfg = I2S_STD_PHILIPS_SLOT_DEFAULT_CONFIG(bits_per_chan, channel_fmt), \
        .gpio_cfg = { \
            .mclk = GPIO_I2S_MCLK, \
            .bclk = GPIO_I2S_SCLK, \
            .ws   = GPIO_I2S_LRCK, \
            .dout = GPIO_I2S_DOUT, \
            .din  = GPIO_I2S_SDIN, \
            .invert_flags = { \
                .mclk_inv = false, \
                .bclk_inv = false, \
                .ws_inv   = false, \
            }, \
        }, \
    }

#else

#define I2S_CONFIG_DEFAULT(sample_rate, channel_fmt, bits_per_chan) { \
    .mode                   = I2S_MODE_MASTER | I2S_MODE_RX, \
    .sample_rate            = 16000, \
    .bits_per_sample        = I2S_BITS_PER_SAMPLE_32BIT, \
    .channel_format         = I2S_CHANNEL_FMT_ONLY_LEFT, \
    .communication_format   = I2S_COMM_FORMAT_STAND_I2S, \
    .intr_alloc_flags       = ESP_INTR_FLAG_LEVEL1, \
    .dma_buf_count          = 6, \
    .dma_buf_len            = 160, \
    .use_apll               = false, \
    .tx_desc_auto_clear     = true, \
    .fixed_mclk             = 0, \
    .mclk_multiple          = I2S_MCLK_MULTIPLE_DEFAULT, \
    .bits_per_chan          = I2S_BITS_PER_CHAN_32BIT, \
}

#endif

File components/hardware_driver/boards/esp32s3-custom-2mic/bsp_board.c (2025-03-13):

/**
 *
 * @copyright Copyright 2021 Espressif Systems (Shanghai) Co. Ltd.
 *
 *      Licensed under the Apache License, Version 2.0 (the "License");
 *      you may not use this file except in compliance with the License.
 *      You may obtain a copy of the License at
 *
 *               http://www.apache.org/licenses/LICENSE-2.0
 *
 *      Unless required by applicable law or agreed to in writing, software
 *      distributed under the License is distributed on an "AS IS" BASIS,
 *      WITHOUT WARRANTIES OR CONDITIONS OF ANY KIND, either express or implied.
 *      See the License for the specific language governing permissions and
 *      limitations under the License.
 */

#include "string.h"
#include "bsp_board.h"
#include "driver/i2s_std.h"
#include "driver/i2s_tdm.h"
#include "soc/soc_caps.h"
#include "driver/gpio.h"
#include "esp_err.h"
#include "esp_log.h"
#include "esp_rom_sys.h"
#include "esp_vfs_fat.h"
#include "sdmmc_cmd.h"
#if ((SOC_SDMMC_HOST_SUPPORTED) && (FUNC_SDMMC_EN))
#include "driver/sdmmc_host.h"
#endif /* ((SOC_SDMMC_HOST_SUPPORTED) && (FUNC_SDMMC_EN)) */

#define GPIO_MUTE_NUM   GPIO_NUM_1
#define GPIO_MUTE_LEVEL 1
#define ACK_CHECK_EN   0x1     /*!< I2C master will check ack from slave*/
#define ADC_I2S_CHANNEL 2
static sdmmc_card_t *card;
static const char *TAG = "board";
static int s_play_sample_rate = 16000;
static int s_play_channel_format = 2;
static int s_bits_per_chan = 24;

static i2s_chan_handle_t                rx_handle = NULL;        // I2S rx channel handler

static esp_err_t bsp_i2s_init(i2s_port_t i2s_num, uint32_t sample_rate, int channel_format, int bits_per_chan)
{
    esp_err_t ret_val = ESP_OK;

    i2s_chan_config_t chan_cfg = I2S_CHANNEL_DEFAULT_CONFIG(i2s_num, I2S_ROLE_MASTER);

    ret_val |= i2s_new_channel(&chan_cfg, NULL, &rx_handle);
    i2s_std_config_t std_cfg = I2S_CONFIG_DEFAULT(16000, I2S_SLOT_MODE_STEREO, I2S_DATA_BIT_WIDTH_32BIT);
    // std_cfg.slot_cfg.slot_mask = I2S_STD_SLOT_LEFT;
    // std_cfg.clk_cfg.mclk_multiple = EXAMPLE_MCLK_MULTIPLE;   //The default is I2S_MCLK_MULTIPLE_256. If not using 24-bit data width, 256 should be enough
    //std_cfg.clk_cfg.mclk_multiple = I2S_MCLK_MULTIPLE_384;
    ret_val |= i2s_channel_init_std_mode(rx_handle, &std_cfg);
    ret_val |= i2s_channel_enable(rx_handle);

    return ret_val;
}

static esp_err_t bsp_i2s_deinit(i2s_port_t i2s_num)
{
    esp_err_t ret_val = ESP_OK;

    ret_val |= i2s_channel_disable(rx_handle);
    ret_val |= i2s_del_channel(rx_handle);
    rx_handle = NULL;

    return ret_val;
}

esp_err_t bsp_get_feed_data(bool is_get_raw_channel, int16_t *buffer, int buffer_len)
{
    esp_err_t ret = ESP_OK;
    size_t bytes_read;
    int audio_chunksize = buffer_len / (sizeof(int32_t) * 2);
    ret = i2s_channel_read(rx_handle, buffer, buffer_len, &bytes_read, portMAX_DELAY);

    int32_t *tmp_buff = buffer;
    for (int i = 0; i < audio_chunksize; i++) {
        tmp_buff[2 * i] = tmp_buff[2 * i] >> 14;
        tmp_buff[2 * i + 1] = tmp_buff[2 * i + 1] >> 14;
    }

    return ret;
}

int bsp_get_feed_channel(void)
{
    return ADC_I2S_CHANNEL;
}

char* bsp_get_input_format(void)
{
    return "MM";
}


esp_err_t bsp_board_init(uint32_t sample_rate, int channel_format, int bits_per_chan)
{
    bsp_i2s_init(I2S_NUM_1, 16000, 2, 32);

    return ESP_OK;
}

esp_err_t bsp_sdcard_init(char *mount_point, size_t max_files)
{
    if (NULL != card) {
        return ESP_ERR_INVALID_STATE;
    }

    /* Check if SD crad is supported */
    if (!FUNC_SDMMC_EN && !FUNC_SDSPI_EN) {
        ESP_LOGE(TAG, "SDMMC and SDSPI not supported on this board!");
        return ESP_ERR_NOT_SUPPORTED;
    }

    esp_err_t ret_val = ESP_OK;

    /**
     * @brief Options for mounting the filesystem.
     *   If format_if_mount_failed is set to true, SD card will be partitioned and
     *   formatted in case when mounting fails.
     *
     */
    esp_vfs_fat_sdmmc_mount_config_t mount_config = {
        .format_if_mount_failed = false,
        .max_files = max_files,
        .allocation_unit_size = 16 * 1024
    };

    /**
     * @brief Use settings defined above to initialize SD card and mount FAT filesystem.
     *   Note: esp_vfs_fat_sdmmc/sdspi_mount is all-in-one convenience functions.
     *   Please check its source code and implement error recovery when developing
     *   production applications.
     *
     */
    sdmmc_host_t host =
#if FUNC_SDMMC_EN
        SDMMC_HOST_DEFAULT();
#else
        SDSPI_HOST_DEFAULT();
    spi_bus_config_t bus_cfg = {
        .mosi_io_num = GPIO_SDSPI_MOSI,
        .miso_io_num = GPIO_SDSPI_MISO,
        .sclk_io_num = GPIO_SDSPI_SCLK,
        .quadwp_io_num = GPIO_NUM_NC,
        .quadhd_io_num = GPIO_NUM_NC,
        .max_transfer_sz = 4000,
    };
    ret_val = spi_bus_initialize(host.slot, &bus_cfg, SPI_DMA_CH_AUTO);
    if (ret_val != ESP_OK) {
        ESP_LOGE(TAG, "Failed to initialize bus.");
        return ret_val;
    }
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

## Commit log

2025-03-13 feat: add raw support for custom esp32s3 boards with 1 microphone
2025-03-13 feat: add raw support for custom esp32s3 boards with 2 microphones
    Removed support for ESP-IDF version 4.4 for this setup
2025-03-15 feat: initialize the module from the example voice_activity_detection
    only for esp32s3 with two INMP441 microphones and ESP-IDF version >= 5.0
2025-03-20 chore: add partitions for sdkconfig
    [partitions.csv, partitions_esp32.csv]
2025-03-20 feat: add SD card support via SPI for debugging
2025-03-28 feat(network): add sending rtp packets via udp to the server
    TODO: replace example connection, resolve issues with delays during startup
    [partitions.csv]
2025-06-25 feat: initial implementation of RTP/UDP audio streaming server
    Add core server functionality including:
    - UDP socket listener on configurable host/port
    - RTP packet parsing and PCM audio decoding
    - PyAudio playback system with buffer management
    - Async file logging of raw PCM data
    - Configuration management via Config class
    - Graceful shutdown handling for SIGINT/SIGTERM
    - Comprehensive input validation and error handling
    - Threaded file I/O operations
    - Type hints throughout codebase
    - Logging system with configurable levels
    Implements basic audio streaming server architecture meeting
    requirements for real-time packet processing and playback
    with necessary reliability measures.
2025-06-26 feat: add pcb (layout and schematic) with README
    [SCH-microphone-module-2025-06-26.schdoc]
2025-06-27 chore: removing unused dependencies
    [partitions.csv, partitions_esp32.csv]
